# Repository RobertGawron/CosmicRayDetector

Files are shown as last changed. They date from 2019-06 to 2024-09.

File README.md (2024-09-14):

# CosmicRayDetector

**This project is unfinished.**

## Purpose

Cosmic radiation consists of a constant stream of high-energy particles originating from deep space. When these particles reach Earth, they collide with atoms in the atmosphere, producing a variety of secondary particles, one of which is the muon. This device is designed to detect these muons using a grid of Geiger tubes, while distinguishing them from Earth's natural background radiation. The goal is to create a more precise muon detection system using digital processing, allowing for enhanced readability and further data analysis on a PC, unlike other projects that rely on analog interfaces.

## Principle of Operation

When cosmic rays strike the Earth's atmosphere, they produce high-speed particles, such as muons, which can be detected by Geiger tubes. Due to their high energy, muons pass through Geiger tubes without being stopped, and if multiple tubes are aligned, a muon passing through one will likely pass through others, registering multiple detections. This behavior distinguishes muons from background radiation, which lacks the energy to penetrate multiple Geiger tubes.

To further reduce interference from background radiation, lead shielding is placed around the Geiger tubes. This setup allows the device to filter out low-energy radioactive particles from Earth's environment, isolating the detection of cosmic muons.

## Actual Hardware Version 

The device is the violet PCB. It probably doesn’t work - I can't say for sure because I forgot to buy all the components.

The story behind this device is actually quite interesting. The first version I created was a very small PCB. Depending on which components were soldered, it could be used in three different ways: as a user interface module (with a 4x4 LED grid and push buttons), to connect the GM tube on the "hot side" (connectors and a resistor to limit pulse current), or on the "cold side" (shunt resistor and ADC). It was a clever design to save money on PCB manufacturing, but it added a lot of complexity during assembly. I quickly realized that saving $10 wasn’t worth adding two hours of soldering work.

In the second version, I used NAND gates as an ADC. While I believe this setup would work, it's a bit too old-school, and it would make much more sense to use comparators instead.

The third version is currently under development.

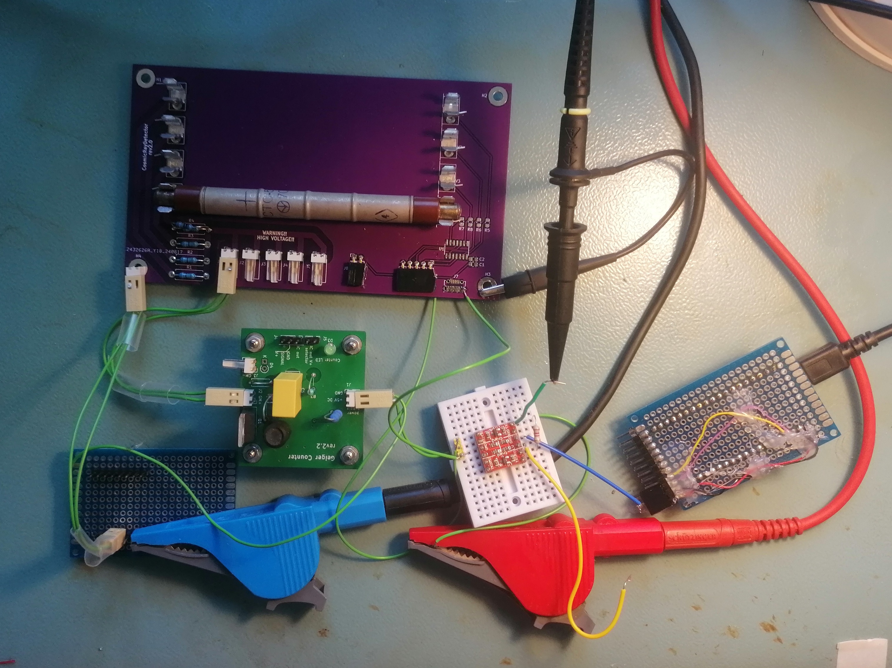
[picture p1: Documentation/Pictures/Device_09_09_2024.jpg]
The device.


As visible on the image, due to forgetting to buy the NAND gates, as a last resort, I attempted to use a high-to-low logic level converter with MOSFETs I had on hand. It didn’t work, and I didn’t have time to investigate further.

## System Architecture

The user interface is still to be determined.

System Architecture.

Tools: PlantUML

## Hardware

* To generate the high voltage required by the Geiger tubes, the [DC/DC converter from this Geiger-Müller counter project](https://github.com/RobertGawron/GeigerMullerCounter) is utilized.
* The Geiger tube model used is the Soviet STS-5 (СТС-5).

Tools: KiCad (for PCB design).

## Software

Software doesn't exists yet.

* The FPGA (Cyclone IV) firmware will be written in Verilog using Quartus Lite as the IDE.
* See [Setting up the development environment on Windows](./wiki/Setting-up-development-environment-on-Windows) for more details.

## Hazards

**Warning: The device operates at high voltage, which can cause serious injury or death. Avoid touching the PCB or Geiger tubes while the device is powered on.**

## License
This project is licensed under the MIT License. See the [LICENSE](./LICENSE) file for details.

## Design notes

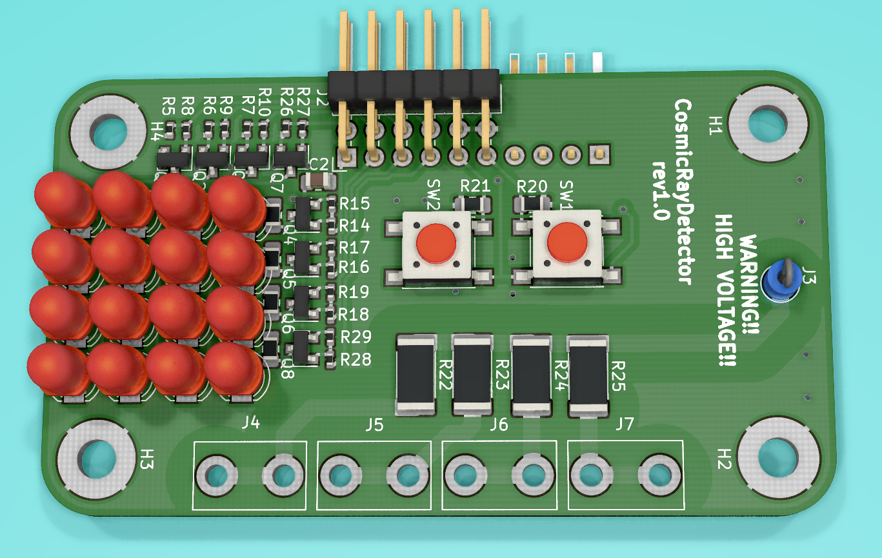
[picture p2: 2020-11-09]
Documentation/Pictures/render_top_09_11_2020.png

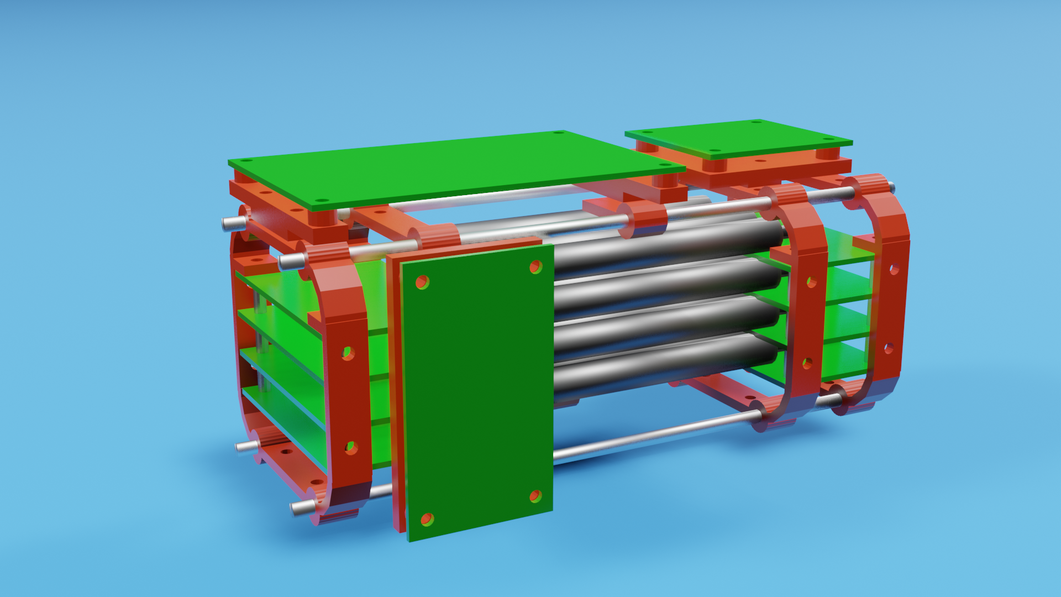
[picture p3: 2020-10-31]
Documentation/Pictures/render_31_10_2020.png

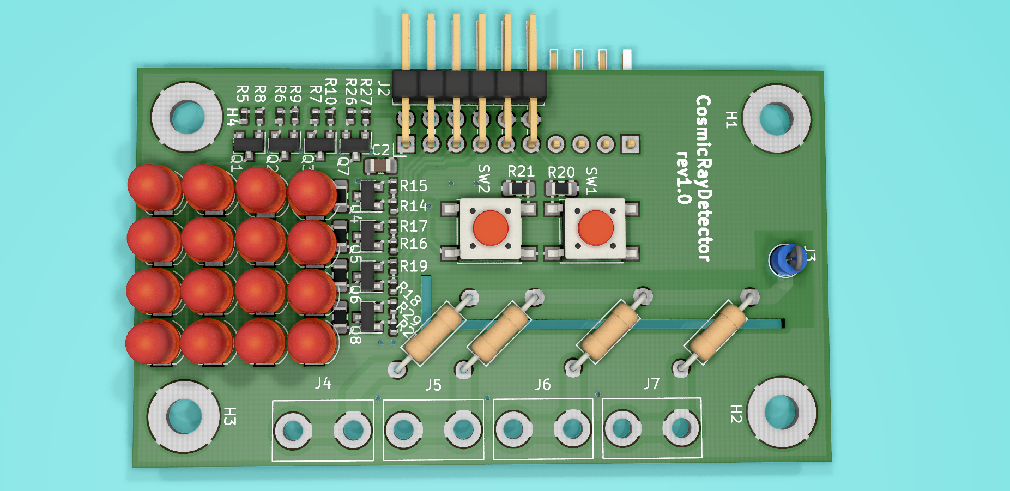
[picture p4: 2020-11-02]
Documentation/Pictures/render_top_02_11_2020.png

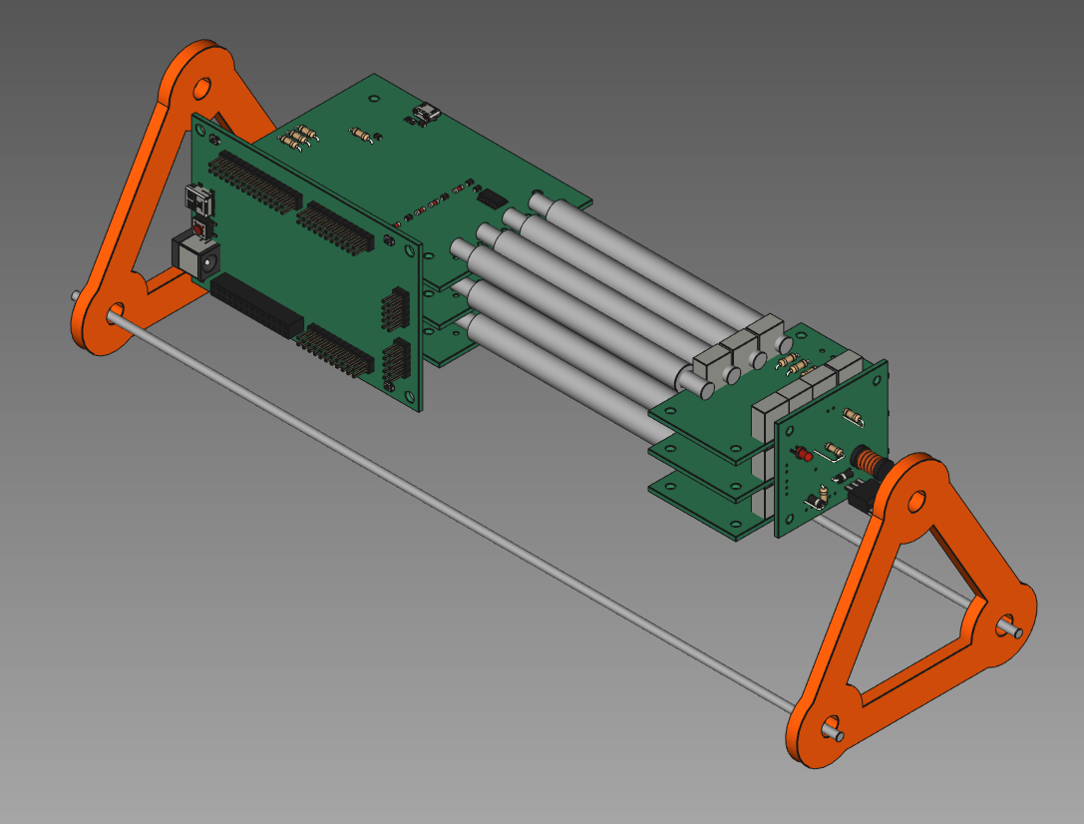
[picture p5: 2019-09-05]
Documentation/Pictures/render_15_09_2019.png

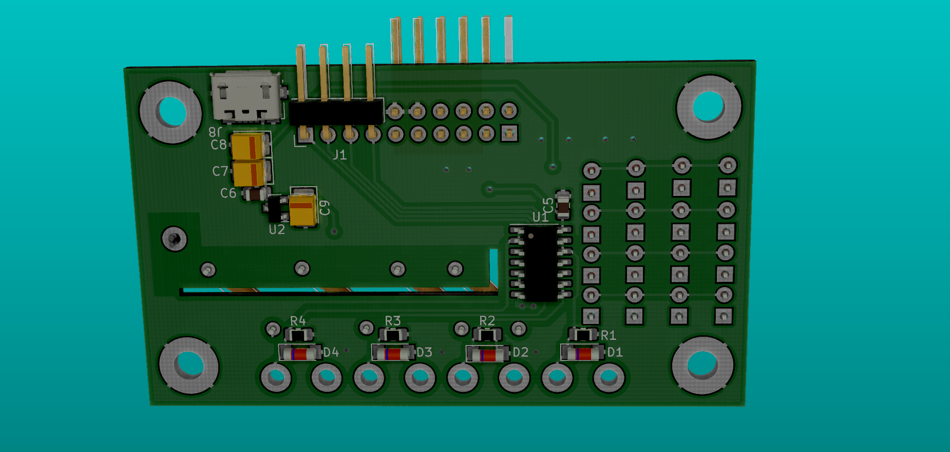
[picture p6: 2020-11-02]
Documentation/Pictures/render_bottom_02_11_2020.png

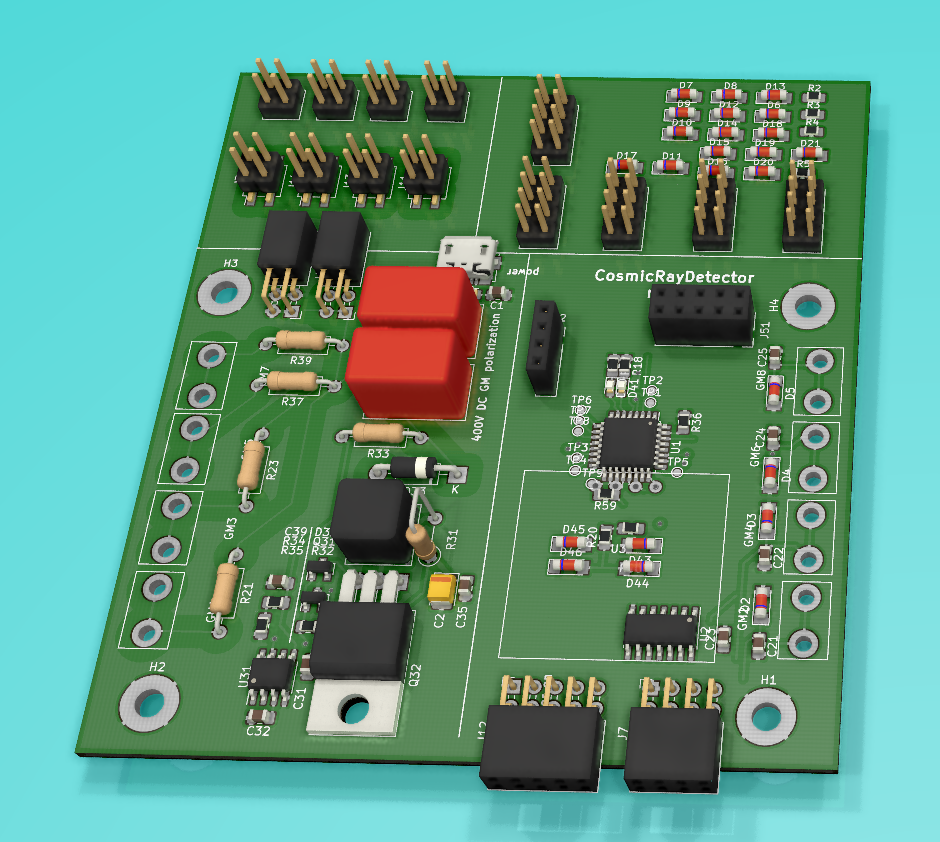
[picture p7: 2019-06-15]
Documentation/Pictures/render_05_06_2019.png

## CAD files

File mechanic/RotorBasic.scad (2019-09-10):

include <Constants.scad>;
include <RotorHandler.scad>;

//rotorBasic();

module rotorBasic(){
    linear_extrude(height = 4, center = true, convexity = 10, twist = 0)
        union(){    
			rotorHandler();
            innerRing();
            ballBearingHandler();
        }
}

module rotorBars(){
    screws(barHoleRadius);    
}

module innerRing(){
    innerRingDiameter = 10;
    circle(innerRingDiameter);  
}



module ballBearingHandler(){
    diameter = 4;
    circle(diameter);       
}

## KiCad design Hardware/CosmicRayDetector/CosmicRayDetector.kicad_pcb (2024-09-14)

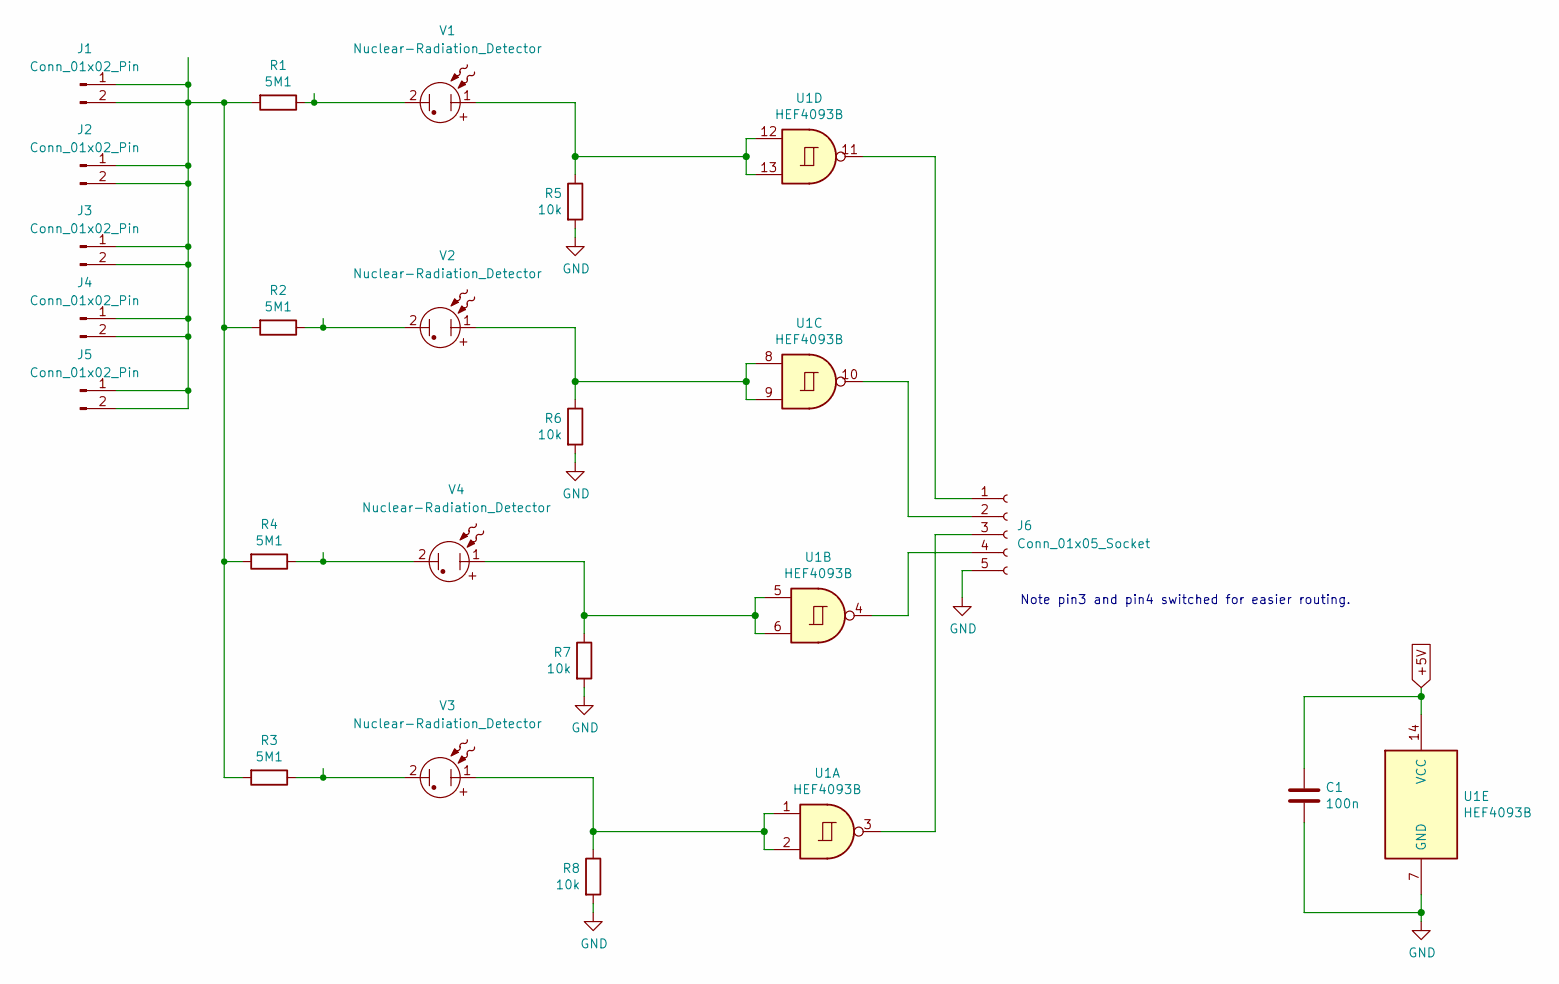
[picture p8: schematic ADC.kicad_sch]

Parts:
C1: 100n; C_0805_2012Metric_Pad1.18x1.45mm_HandSolder
J1, J2, J3, J4, J5: Conn_01x02_Pin; PinSocket_1x02_P2.54mm_Horizontal
J6: Conn_01x05_Socket; PinHeader_1x05_P2.54mm_Horizontal
R1, R2, R3, R4: 5M1; R_Axial_DIN0411_L9.9mm_D3.6mm_P12.70mm_Horizontal
R5, R6, R7, R8: 10k; R_0805_2012Metric_Pad1.20x1.40mm_HandSolder
U1: HEF4093B; SOIC-14_3.9x8.7mm_P1.27mm
V1, V2, V3, V4: Nuclear-Radiation_Detector; GeigerTube

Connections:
+5V: C1.1, U1.14 (VCC); also elsewhere on the board
GND: C1.2, J6.5, R5.2, R6.2, R7.2, R8.2, U1.7 (GND); also elsewhere on the board
unnamed: J1.1, J1.2, J2.1, J2.2, J3.1, J3.2, J4.1, J4.2, J5.1, J5.2, R1.2, R2.2, R3.2, R4.2
unnamed: J6.1, U1.11
unnamed: J6.2, U1.10
unnamed: J6.3, U1.3
unnamed: J6.4, U1.4
unnamed: R1.1, V1.2
unnamed: R2.1, V2.2
unnamed: R3.1, V3.2
unnamed: R4.1, V4.2
unnamed: R5.1, U1.12, U1.13, V1.1
unnamed: R6.1, U1.8, U1.9, V2.1
unnamed: R7.1, U1.5, U1.6, V4.1
unnamed: R8.1, U1.1, U1.2, V3.1

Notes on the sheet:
Note pin3 and pin4 switched for easier routing.

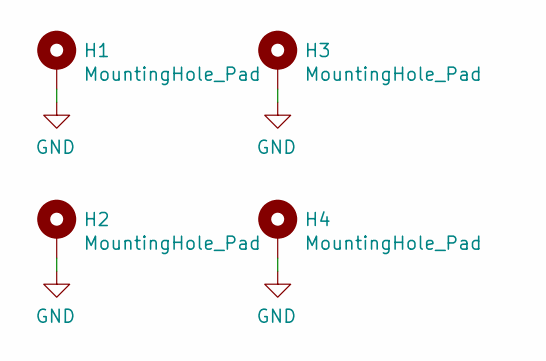
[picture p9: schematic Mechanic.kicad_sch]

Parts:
H1, H2, H3, H4: MountingHole_Pad; MountingHole_3.5mm_Pad

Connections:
GND: H1.1, H2.1, H3.1, H4.1; also elsewhere on the board

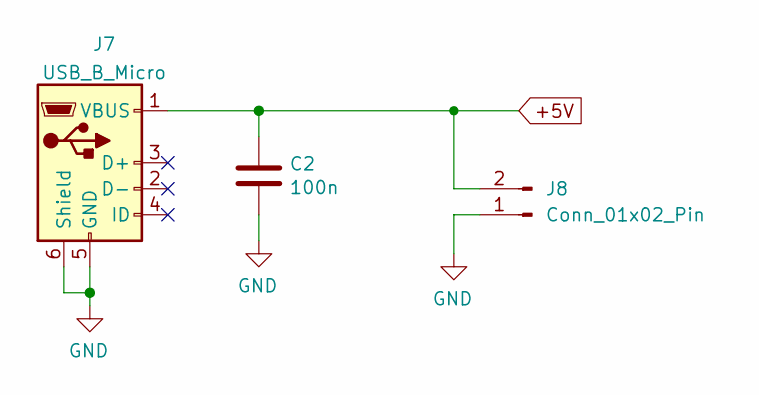
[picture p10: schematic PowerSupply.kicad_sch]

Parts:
C2: 100n; C_0805_2012Metric_Pad1.18x1.45mm_HandSolder
J7: USB_B_Micro; USB_Micro-B_Molex-105017-0001
J8: Conn_01x02_Pin; PinSocket_1x02_P2.54mm_Horizontal

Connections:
+5V: C2.1, J7.1 (VBUS), J8.2; also elsewhere on the board
GND: C2.2, J7.5 (GND), J7.6 (Shield), J8.1; also elsewhere on the board

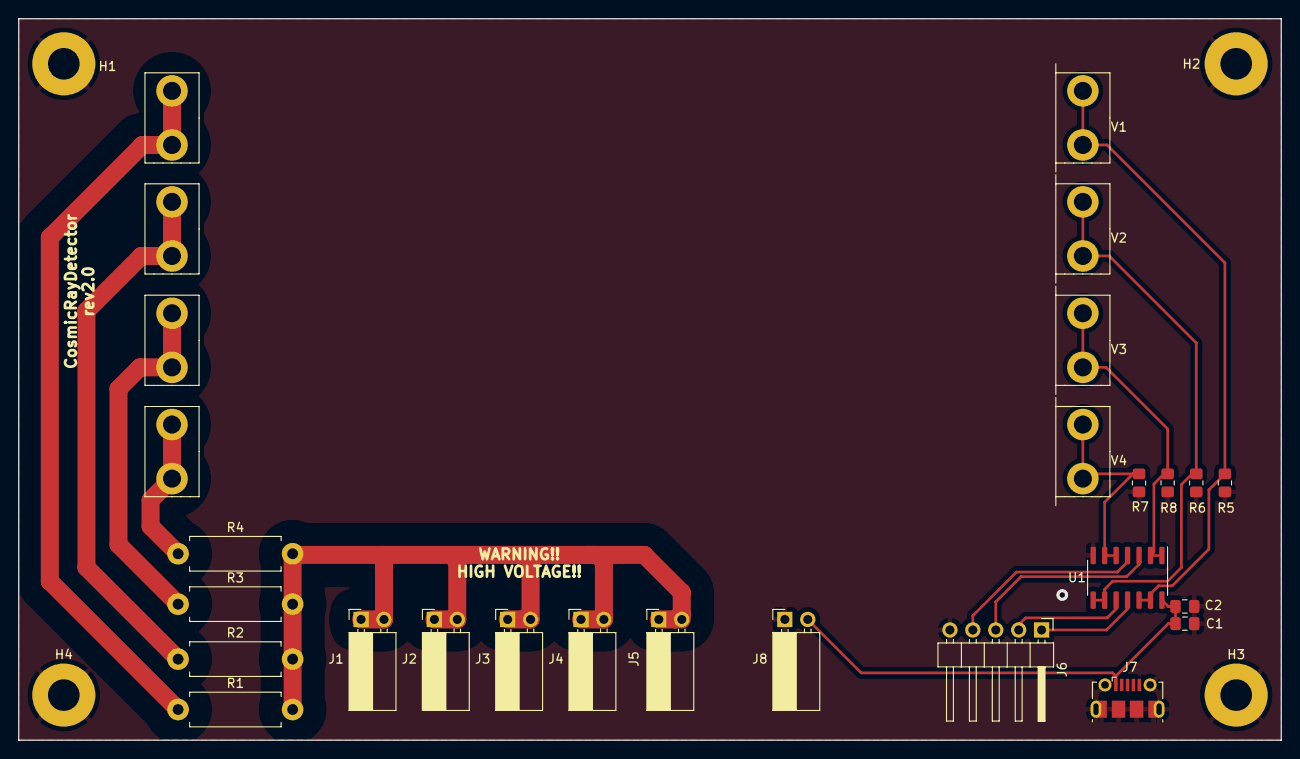
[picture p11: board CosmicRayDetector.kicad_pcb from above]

Board: 2 copper layers, 140.0 x 80.0 mm, 27 parts (0 on the bottom side), 15 nets.

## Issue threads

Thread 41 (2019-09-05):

Select 5V, 3V3 DC/DC converters to be used.

RobertGawron, 2019-09-05:

RobertGawron, 2019-09-05:
Blocked by #56

RobertGawron, 2020-10-31:
Solved by #56

Closed 2020-10-31.

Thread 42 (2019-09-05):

Add option to mount either 3 or 4 GM tubes on PCB and still to be aligned with center of PCB

RobertGawron, 2019-09-05:
Needed to simplify math when tubes will rotate.

RobertGawron, 2020-10-31:
Step motor idea was abandoned, so no need for such design.

Closed 2020-10-31.

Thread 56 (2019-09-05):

How to power the FPGA board from li-ion batteries?

RobertGawron, 2019-09-05:
What voltages are needed? Is 5V only option?

RobertGawron, 2020-10-31:
Step motor idea was abandoned, so no need for li-ion batteries.

Closed 2020-10-31.

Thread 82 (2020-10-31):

When PCB design is done, update mechanical design

RobertGawron, 2020-10-31:
In __mechanical overview__, fix size of bar used for mounting PCB.

Closed 2021-07-17.

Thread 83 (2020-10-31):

Fix design of a bar mounting to rods used for FPGA holder

RobertGawron, 2020-10-31:
Visible on the render, it's incorrect.

RobertGawron, 2024-09-09:
Not needed.

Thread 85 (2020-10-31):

Update detector PCB after mechanical overview was done.

RobertGawron, 2020-10-31:
- add space around mounting holes
- add connectors for FPGA
- add display (4x4 LEDs)
- update docs (mention one PCB is used in three variants)

RobertGawron, 2020-11-02:
Done in 0866eb42c1e63a207a5096ff89943e5316ca684f

Closed 2020-11-02.

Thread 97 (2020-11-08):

Improve PCB design

RobertGawron, 2020-11-08:
1. Remove cutout zone for HV resistors, it's not needed.
2. Space HV resistor in the same distance.
3, Set correct cleanness for HV components.
4. Re-check if diodes are spaced in the same way both horizontally and vertically.
5. GM_CONNECTOR_[x] tracks should be the same width as those for HV resistors.

Closed 2020-11-09.

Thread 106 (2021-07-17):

Avoid using R_2512_6332Metric footprint and use something more popular

RobertGawron, 2021-07-17:

RobertGawron, 2021-07-17:
done

Closed 2021-07-17.

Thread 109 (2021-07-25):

Modify routing to avoid problems during automatic assembly

RobertGawron, 2021-07-25:

Closed 2021-07-25.

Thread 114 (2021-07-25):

Test correctness of the device from electronic pov

RobertGawron, 2021-07-25:

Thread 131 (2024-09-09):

Footprint for GM tube has incorrect length (it's to short)

RobertGawron, 2024-09-09:

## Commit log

2019-06-15 revision 1.0 (reworked git history)
    [AnalogFrontend.sch, BoardConnector.sch, CosmicRayDetector.kicad_pcb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]
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2019-09-01 draft of mechanical paer
    [chassis.FCStd]
2019-09-01 dummy shape
    [SensorRotator.FCStd, chassis.FCStd]
2019-09-02 draft of gm tube
    [SensorRotator.FCStd]
2019-09-02 middle part of gm tube
    [SensorRotator.FCStd]
2019-09-02 gm tube body dimensions fized
    [SensorRotator.FCStd]
2019-09-02 correct gm tube model
    [SensorRotator.FCStd]
2019-09-02 more intuitive subparts names
    [SensorRotator.FCStd]
2019-09-02 rouch view ow the device will looks like
    [SensorRotator.FCStd]
2019-09-03 correct import of pcb
    [SensorRotator.FCStd]
2019-09-03 removed parts not needed due to fpga use
    [AnalogFrontend.sch, BoardConnector.sch, CosmicRayDetector.kicad_pcb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]
2019-09-03 sheets updated to current design
    [ADC.sch, BoardConnector.sch, CosmicRayDetector.kicad_pcb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]
2019-09-03 pcb dimension and socket holes placement
    [CosmicRayDetector.kicad_pcb]
2019-09-03 crd, hw power, gm tube placed roughly ok
    [SensorRotator.FCStd]
2019-09-03 3d model for GM connector
    [Cube.step, GMHandlerFootprint.FCStd]
2019-09-04 added li-ion charger
    [ADC.sch, CosmicRayDetector.kicad_pcb, CosmicRayDetector.sch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]
2019-09-04 added sheet for movement controol
    [CosmicRayDetector.sch, MovementController.sch]
2019-09-05 draft of a holder
    [SensorRotator.FCStd]
2019-09-05 completed draft of a holder on bearing side
    [SensorRotator.FCStd]
2019-09-05 added screw taps
    [SensorRotator.FCStd]
2019-09-05 perspective change
    [SensorRotator.FCStd]
2019-09-05 fix #43
    [HighVoltageGMConnector.kicad_pcb, HighVoltageGMConnector.sch]
2019-09-05 folder structure simplification
    [HighVoltageGMConnector.kicad_pcb, HighVoltageGMConnector.sch]
2019-09-05 added GM VH connector board
    [SensorRotator.FCStd]
2019-09-05 handler resized
    [SensorRotator.FCStd]
2019-09-05 fpga board mockup for freecad
    [FPGABoardMockup.kicad_pcb, FPGABoardMockup.sch]
2019-09-05 added fpga board mock
    [SensorRotator.FCStd]
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2019-09-06 fix #55
    [FPGABoardMockup.kicad_pcb]
2019-09-06 imported fpga board
    [SensorRotator.FCStd]
2019-09-06 sketch created
    [SensorRotator.FCStd]
2019-09-06 paritialy added screw mounting points
    [SensorRotator.FCStd]
2019-09-06 holes for scre placed correctly
    [SensorRotator.FCStd]
2019-09-06 constrains to mounting holes
    [SensorRotator.FCStd]
2019-09-06 i give up, the wheel is good enough
    [SensorRotator.FCStd]
2019-09-06 rotor screws in correct place
    [SensorRotator.FCStd]
2019-09-06 changed 3d printg color to more apealing
    [SensorRotator.FCStd]
2019-09-06 changed gm tube color and material
    [SensorRotator.FCStd]
2019-09-06 draft of step motor driver
    [ADC.sch, CosmicRayDetector.sch, MovementController.sch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]
2019-09-08 fixed file name
    [RearStator.scad]
2019-09-08 fixed size
    [RearStator.scad]
2019-09-08 folder structure cleanup
    [Cube.step, GMHandlerFootprint.FCStd, RearBasic.scad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]
2019-09-09 scad files refactored to sepatrate modules
    [Chassis.scad, RotorBasic.scad, SensorRotator.FCStd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]
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2019-09-09 refactored hardcoded values and variable names
    [Chassis.scad, Constants.scad, RotorBasic.scad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]
2019-09-09 draft of gm counter holder
    [Chassis.scad, GMHolder.scad, RotorBasic.scad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]
2019-09-10 cleaned rotor related files
    [Chassis.scad, GMHolder.scad, RotorBasic.scad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]
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2019-09-10 holder for gm counter
    [Chassis.scad, HighVoltageGeneratorHolder.scad, RotorHandler.scad]
2019-09-10 fixed incorrect dimensions
    [Chassis.scad, HighVoltageGeneratorHolder.scad, RotorHandler.scad]
2019-09-11 added/removed new lines to make consistent
    [Constants.scad, GMTube.scad, HighVoltageGMConnectorHolder.scad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]
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2019-09-29 use stl imported models for better render quality
    [Chassis.scad, CosmicRayDetector.scad, CosmicRayDetector.stl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]
2019-10-12 improved naming, removed tabs
    [Chassis.scad, GenericRotor.scad, GenericStator.scad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]
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2019-10-12 fixed all tabs to spaces
    [GMTube.scad, GenericRotorToStatorConnector.scad, HighVoltageGMConnectorHolder.scad]
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2020-10-28 folder structure cleanup, move from travis to github actions
    [ADC.sch, Chassis.scad, Constants.scad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]
2020-10-29 add design files for mechanic overview
    [Chassis.scad, Constants.scad, DataAcquisitionHolder.scad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]
2020-10-30 decrease physical dimmensions of the device (not completed)
    [DataAcquisitionHolder.scad, DisplayHolder.scad, FPGA.scad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]
2020-10-31 finished mechanical overview design
    [DisplayHolder.scad, FPGA.scad, FPGABoardMockup.kicad_pcb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]
2020-10-31 Add render of the mechanical overview.
    [CosmicRayDetector.stl, FPGABoardMockup.stl, HighVoltageGMConnector.stl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]
2020-11-01 fix #54, fix: #84
    [ADC.sch, CosmicRayDetector.kicad_pcb, CosmicRayDetector.sch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]
2020-11-01 finished design of electronic circuit for detector
    [ADC.sch, CosmicRayDetector.kicad_pcb, CosmicRayDetector.sch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]
2020-11-01 done component placement on pcb and a draft of routing
    [ADC.sch, CosmicRayDetector.kicad_pcb, GMTubeConnector.sch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]
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2020-11-09 Improve PCB design (fix: #97)
    [ADC.sch, CosmicRayDetector.kicad_pcb, HVConnector.sch]
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2021-07-17 fix #103 #104 #105 #106
    [CosmicRayDetector.kicad_pcb, HVConnector.sch]
2021-07-25 fix #109, fix #110
    [CosmicRayDetector.kicad_pcb]
2021-08-15 cleanup after transition to KiCad6
    [ADC.kicad_sch, ADC.sch, CosmicRayDetector.kicad_pcb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]
2022-08-03 added list of componnts t be bought and links where to buy them, todo: find a way to do it from kicad directly
    [CosmicRayDetector.xlsx]
2022-08-06 split pcb dsign to separate pcbs
    [ADC.kicad_sch, CosmicRayDetector.csv, CosmicRayDetector.kicad_pcb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]
2022-08-20 split PCB into separate designs
    [ADC.kicad_sch, Acquisition.kicad_sch, CosmicRayDetector.kicad_pcb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]
2022-08-25 unify all boards into a single one again, but eliminate connectors and dcrease number of mechanical parts
    [ADC.kicad_sch, Acquisition.kicad_sch, Detector.kicad_sch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]
2024-09-14 add hw version 3.0
    [ADC.kicad_sch, CosmicRayDetector.kicad_pcb, CosmicRayDetector.kicad_sch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]
